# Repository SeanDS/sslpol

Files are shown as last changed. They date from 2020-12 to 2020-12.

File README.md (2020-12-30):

# sslpol
Point of load DC-DC converter for powering a Raspberry Pi Zero and peripherals.

This circuit contains a Texas Instruments LMR33640 synchronous buck converter to convert a 6-36 VDC input to a
(nominally) 5 VDC @ up to 4 A output. The design is based on datasheet recommendations. It also includes a
footprint for a Raspberry Pi Zero to be attached on the rear side, face-down, and the 5 VDC rail provides it
with power. This allows a Raspberry Pi and a large external load (such as a string of LEDs) to be powered
from one supply, overcoming the 500 mA current limit from the Pi's 5 VDC rail.

## Features
- 1-24 VDC @ up to 4 A output, configurable via resistors
- 3.8-36 VDC input range
- Header for a Raspberry Pi Zero with its 5 VDC rail attached to the output of the converter (warning: only use
  a Raspberry Pi when the output is configured to be 5 VDC, via R2 and R3)
- Headers for attached devices using SPI, I2C and FTDI protocols
- Converter pin compatibility with the LMR33610, LMR33620, LMR33630, LMR36510 and LMR36520
- Small footprint 30 × 65 mm board

## Schematic


## Board
sslpol

## Credits
Sean Leavey  
https://attackllama.com/

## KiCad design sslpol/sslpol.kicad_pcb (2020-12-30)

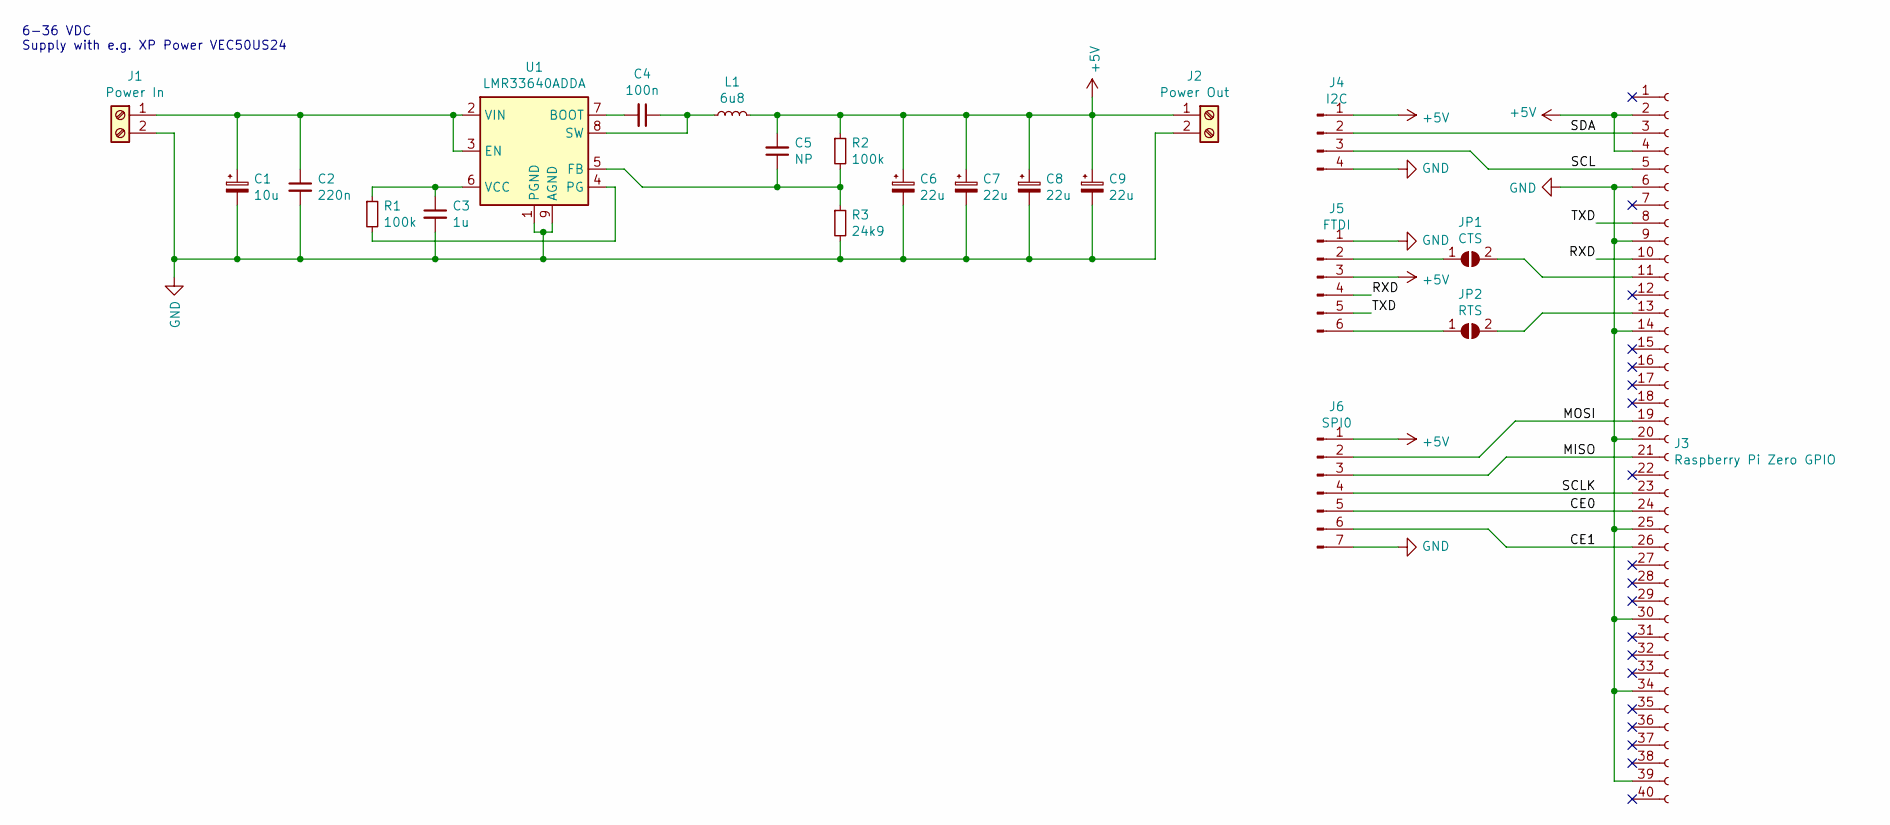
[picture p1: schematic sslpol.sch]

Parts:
C1: 10u; CP_Radial_D5.0mm_P2.00mm
C2: 220n; C_0805_2012Metric
C3: 1u; C_0805_2012Metric
C4: 100n; C_0805_2012Metric
C5: NP; C_0805_2012Metric
C6, C7, C8, C9: 22u; CP_Radial_D6.3mm_P2.50mm; MPN1 ESY226M063AE3AA
J1: Power In; TerminalBlock_Phoenix_MKDS-3-2-5.08_1x02_P5.08mm_Horizontal
J2: Power Out; TerminalBlock_Phoenix_MKDS-3-2-5.08_1x02_P5.08mm_Horizontal
J3: Raspberry Pi Zero GPIO; Raspberry_Pi_Zero_Socketed_THT_FaceDown_MountingHoles
J4: I2C; PinHeader_1x04_P1.27mm_Vertical
J5: FTDI; PinHeader_1x06_P1.27mm_Vertical
J6: SPI0; PinHeader_1x07_P1.27mm_Vertical
JP1: CTS; SolderJumper-2_P1.3mm_Open_RoundedPad1.0x1.5mm
JP2: RTS; SolderJumper-2_P1.3mm_Open_RoundedPad1.0x1.5mm
L1: 6u8; L_Bourns_SRP7028A_7.3x6.6mm; MPN1 SRP7028C-6R8M
R1, R2: 100k; R_0805_2012Metric
R3: 24k9; R_0805_2012Metric
U1: LMR33640ADDA; Texas_HSOP-8-1EP_3.9x4.9mm_P1.27mm_ThermalVias

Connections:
+5V: C5.2, C6.1, C7.1, C8.1, C9.1, J2.1, J3.2, J3.4, J4.1, J5.3, J6.1, L1.2, R2.1
/CE0: J3.24, J6.5
/CE1: J3.26, J6.6
/MISO: J3.21, J6.3
/MOSI: J3.19, J6.2
/RXD: J3.10, J5.4
/SCL: J3.5, J4.3
/SCLK: J3.23, J6.4
/SDA: J3.3, J4.2
/TXD: J3.8, J5.5
GND: C1.2, C2.2, C3.2, C6.2, C7.2, C8.2, C9.2, J1.2, J2.2, J3.6, J3.9, J3.14, J3.20, J3.25, J3.30, J3.34, J3.39, J4.4, J5.1, J6.7, R3.2, U1.1 (PGND), U1.9 (AGND)
unnamed: C1.1, C2.1, J1.1, U1.2 (VIN), U1.3 (EN)
unnamed: C3.1, R1.1, U1.6 (VCC)
unnamed: C4.1, L1.1, U1.8 (SW)
unnamed: C4.2, U1.7 (BOOT)
unnamed: C5.1, R2.2, R3.1, U1.5 (FB)
unnamed: J3.11, JP1.2 (B)
unnamed: J3.13, JP2.2 (B)
unnamed: J5.2, JP1.1 (A)
unnamed: J5.6, JP2.1 (A)
unnamed: R1.2, U1.4 (PG)

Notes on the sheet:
6-36 VDC Supply with e.g. XP Power VEC50US24

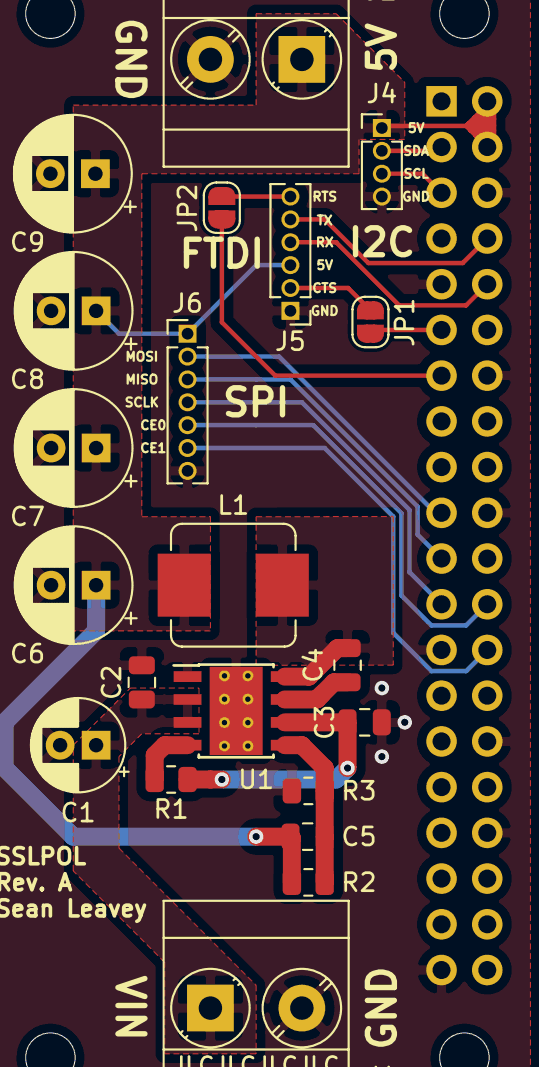
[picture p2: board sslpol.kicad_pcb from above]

Board: 2 copper layers, 22 parts (1 on the bottom side), 21 nets.
